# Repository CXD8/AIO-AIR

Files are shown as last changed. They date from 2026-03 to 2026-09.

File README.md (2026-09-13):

# AIO-AIR
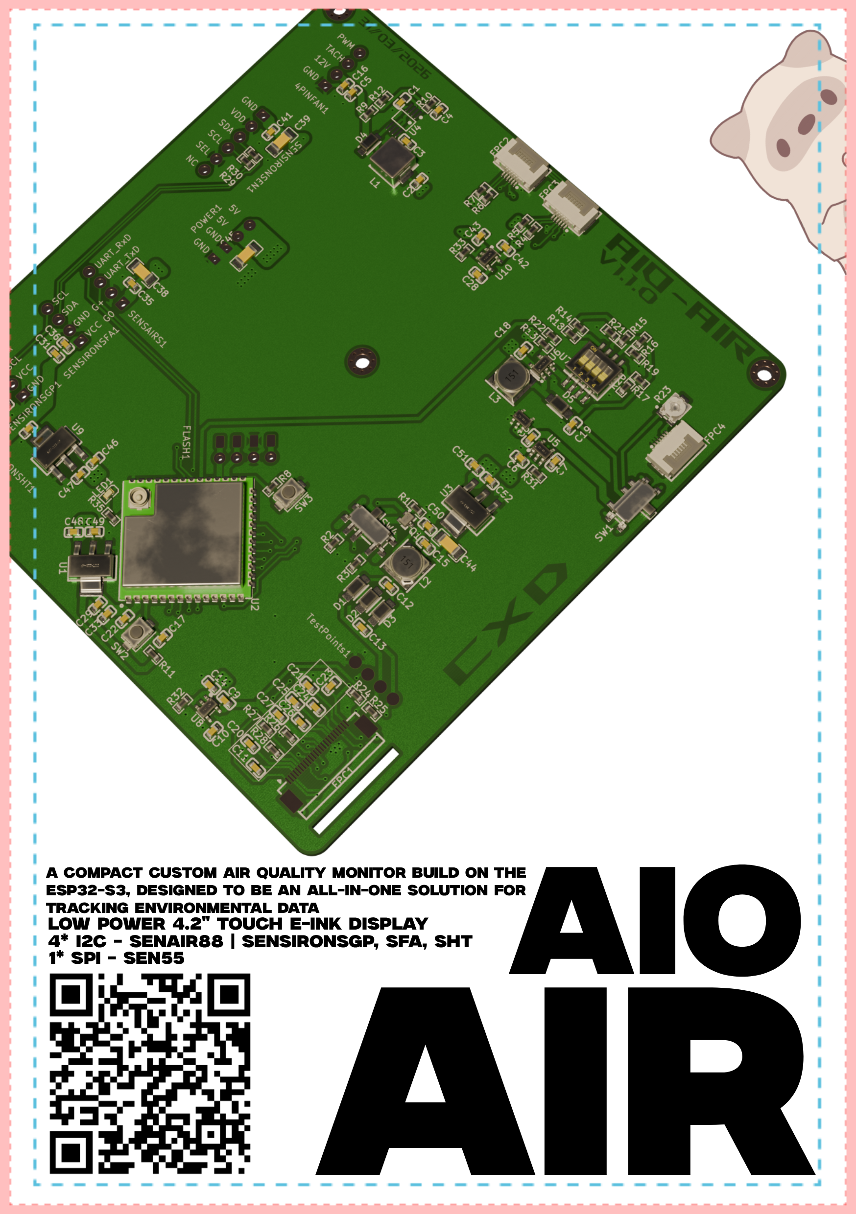
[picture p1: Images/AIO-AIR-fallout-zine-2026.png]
Poster
 \
**Project Overview**\
This is a compact, custom air quality monitor built around the ESP32-S3. I designed it to be an all-in-one solution for tracking environmental data, giving me a much better understanding of the air quality in my workspace.\
## Disclaimer
- **This project is intended for educational and research purposes only**
- **The author accepts no liability for regulatory non-compliance resulting from use of this project**
- **Users are solely responsible for ensuring compliance with all applicable local laws and regulations**
This project is provided **as-is, with absolutely no warranty of any kind**, express or implied. The author(s) accept **zero responsibility or liability** for any outcome resulting from the use, assembly, or operation of this hardware - including but not limited to property damage, fire, personal injury, or death.

**Use entirely at your own risk. The author(s) have no responsibility whatsoever for anything that goes wrong.**
- **Regulatory Disclaimer**
This project may use uncertified radio frequency (RF) modules. These components may have not been independently tested or certified for compliance such as for FCC (USA), CE (EU), or any other regulatory framework.
ard.**. The author(s) accept no responsibility for any damage, injury, or death caused.
- **No certification.** This design has not been tested, certified, or approved for any commercial, consumer, safety-critical, or regulatory-controlled application.
- **No guarantees.** The author(s) make no guarantees regarding the accuracy or fitness for purpose of the schematic, BOM, firmware, or any associated documentation.
**By using, building, or operating this project in any form, you accept full and sole responsibility for all risks and any consequences that arise.**
By using this project in any form, you agree to assume all associated risks and responsibilities.

**How to Use**\
Flashing: No integrated usb flashing feature. You can use your choice of usb flashing device eg FT or CH chipsets, connect them respectively on the PCB via the headers. Copy firmware into Ardiuno IDE or preffered flashing software, then flash directly.\
Integration: The device is built to talk directly to Home Assistant via ESPHome/MQTT. Once you flash the firmware, it will show up as a sensor entity on your dashboard.\
Features: You can view real-time data on your dashboard or through the low power e ink display. Optional fan with control and speed, status etc. Flexible desing, connect any device to the respective power, uart or spi pins.\

**Why I Built This**\
Many makers do soldering, 3D printing, and working with various materials in an enclosed space.I designed this board to get accurate, reliable readings so I can actually manage the air quality while I work. Also for monitoring Co2 because sleep is important :) |
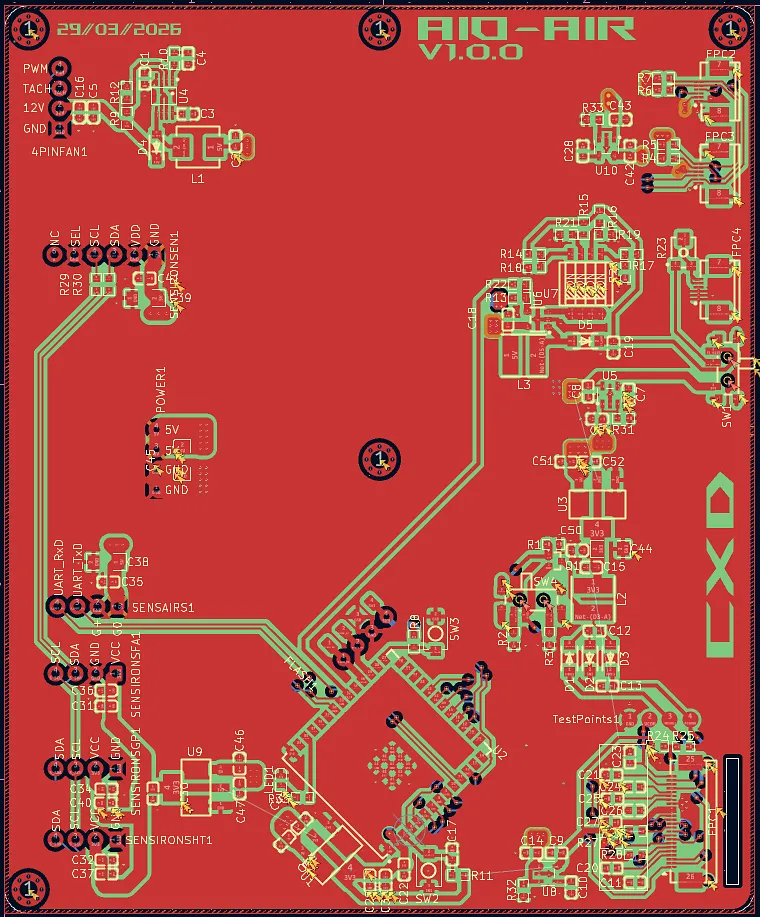
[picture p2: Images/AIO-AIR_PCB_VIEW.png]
PCB_VIEW
 \

Bill Of Materials
| **#** | **bom\.csv** | ****  | ****  | **** | **** | ****  | **** | **** | **** | **** | **** | **** | **** | **** | **** | **** | **** | **** | **** | **** | **** | **** | **** | **** | **** | **** |
|---|---|---|---|---|---|---|---|---|---|---|---|---|---|---|---|---|---|---|---|---|---|---|---|---|---|---|
| 1 | | | | | | | | | | | BOM Date Created:23/05/26 | | | | BOM Export Date: 23/05/26 | | | | | | | | | | | |
| 2 | | | | | | | | | | | EST LCSC TOTAL: $30\.73 | | | | | | | | | | | | | | | |
| 3 | | | | | | | | | | | TOTAL – 1 SEN55 Sensor: $92\.61 | | | | | | | | | | | | | | | |
| 4 | Uploaded data | | | | | | | | | | LCSC Matching Results | | | | | | | | | | | | | | | |
| 5 | LCSC\# | Mfr\. | Mrf\# | Description | Package | Value | Customer Part Number | Quantity | Target Price\(USD\) | Target Lead Time\(Business Days\) | Mrf\# | Mfr\. | Order Qty\. | Unit Price\(USD\) | Ext\.Price\(USD\) | LCSC\# | Package | Min  | Mult | SPQ  | Availability | Stock Status  | Customer Notes | Description | Matched status | Product Link |
| 6 | C15849 | | | | C0603 | | \- | 11 | | | CL10A105KB8NNNC | Samsung Electro\-Mechanics | 50 | 0\.0077 | 0\.39 | C15849 | 0603 | 50 | 50 | 4000 | 4032550 | In Stock | | 1uF ±10% 50V Ceramic Capacitor X5R 0603 | Exact Matches  | https://www\.lcsc\.com/product\-detail/C15849\.html |
| 7 | C96446 | | | | C0603 | | \- | 10 | | | CL10A106MA8NRNC | Samsung Electro\-Mechanics | 20 | 0\.0223 | 0\.45 | C96446 | 0603 | 20 | 20 | 4000 | 277300 | In Stock | | 10uF ±20% 25V Ceramic Capacitor X5R 0603 | Exact Matches  | https://www\.lcsc\.com/product\-detail/C96446\.html |
| 8 | C1591 | | | | C0603 | | \- | 10 | | | CL10B104KB8NNNC | Samsung Electro\-Mechanics | 100 | 0\.0032 | 0\.32 | C1591 | 0603 | 100  | 100  | 4000 | 1456500 | In Stock | | 100nF ±10% 50V Ceramic Capacitor X7R 0603 | Exact Matches  | https://www\.lcsc\.com/product\-detail/C1591\.html |
| 9 | C307467 | | | | C0603 | | \- | 4 | | | CL10A475KL8NRNC | Samsung Electro\-Mechanics | 5 | 0\.0304 | 0\.15 | C307467 | 0603 | 5 | 5 | 4000 | 192075 | In Stock | | 4\.7uF ±10% 35V Ceramic Capacitor X5R 0603 | Exact Matches  | https://www\.lcsc\.com/product\-detail/C307467\.html |
| 10 | C883598 | | | | C1206 | | \- | 4 | | | GRM31CR61A107MEA8L | muRata | 5 | 0\.1955 | 0\.98 | C883598 | 1206 | 5 | 5 | 2000 | 209960 | In Stock | | 100uF ±20% 10V Ceramic Capacitor X5R 1206 | Exact Matches  | https://www\.lcsc\.com/product\-detail/C883598\.html |
| 11 | C21122 | | | | C0603 | | \- | 3 | | | CL10B223KB8NNNC | Samsung Electro\-Mechanics | 50 | 0\.0046 | 0\.23 | C21122 | 0603 | 50 | 50 | 4000 | 1335100 | In Stock | | 22nF ±10% 50V Ceramic Capacitor X7R 0603 | Exact Matches  | https://www\.lcsc\.com/product\-detail/C21122\.html |
| 12 | C307467 | | | | C0603 | | \- | 3 | | | CL10A475KL8NRNC | Samsung Electro\-Mechanics | 5 | 0\.0304 | 0\.15 | C307467 | 0603 | 5 | 5 | 4000 | 192075 | In Stock | | 4\.7uF ±10% 35V Ceramic Capacitor X5R 0603 | Exact Matches  | https://www\.lcsc\.com/product\-detail/C307467\.html |
| 13 | C6119851 | | | | C0603 | | \- | 2 | | | CGA0603X5R475K350JT | HRE | 20 | 0\.0304 | 0\.61 | C6119851  | 0603 | 20 | 20 | 4000 | 18100 | In Stock | | 4\.7uF ±10% 35V Ceramic Capacitor X5R 0603 | Exact Matches  | https://www\.lcsc\.com/product\-detail/C6119851\.html  |
| 14 | C1591 | | | | C0603 | | \- | 2 | | | CL10B104KB8NNNC | Samsung Electro\-Mechanics | 100 | 0\.0032 | 0\.32 | C1591 | 0603 | 100  | 100  | 4000 | 1456500 | In Stock | | 100nF ±10% 50V Ceramic Capacitor X7R 0603 | Exact Matches  | https://www\.lcsc\.com/product\-detail/C1591\.html |
| 15 | C6563232 | | | | C0603 | | \- | 1 | | | 0603B112K500NT | FH | 100 | 0\.0030 | 0\.30 | C6563232  | 0603 | 100  | 100  | 4000 | 400 | In Stock | | 1\.1nF ±10% 50V Ceramic Capacitor X7R 0603 | Exact Matches  | https://www\.lcsc\.com/product\-detail/C6563232\.html  |
| 16 | C1591 | | | | C0603 | | \- | 1 | | | CL10B104KB8NNNC | Samsung Electro\-Mechanics | 100 | 0\.0032 | 0\.32 | C1591 | 0603 | 100  | 100  | 4000 | 1456500 | In Stock | | 100nF ±10% 50V Ceramic Capacitor X7R 0603 | Exact Matches  | https://www\.lcsc\.com/product\-detail/C1591\.html |
| 17 | C86295 | | | | C0603 | | \- | 1 | | | CL10A226MP8NUNE | Samsung Electro\-Mechanics | 10 | 0\.0157 | 0\.16 | C86295 | 0603 | 10 | 10 | 3000 | 1989760 | In Stock | | 22uF ±20% 10V Ceramic Capacitor X5R 0603 | Exact Matches  | https://www\.lcsc\.com/product\-detail/C86295\.html |
| 18 | C98220 | | | | R0603 | | \- | 5 | | | RC0603FR\-0710KL | YAGEO | 100 | 0\.0015 | 0\.15 | C98220 | 0603 | 100  | 100  | 5000 | 0 | Backordered | | 100mW 10k? 75V Thick Film Resistor ±100ppm/? ±1% 0603 Chip Resistor \- Surface Mount RoHS | Exact Matches  | https://www\.lcsc\.com/product\-detail/C98220\.html |
| 19 | C14675 | | | | R0603 | | \- | 5 | | | RC0603FR\-07100KL | YAGEO | 100 | 0\.0014 | 0\.14 | C14675 | 0603 | 100  | 100  | 5000 | 1073900 | In Stock | | 100mW 100k? 75V Thick Film Resistor ±100ppm/? ±1% 0603 Chip Resistor \- Surface Mount RoHS | Exact Matches  | https://www\.lcsc\.com/product\-detail/C14675\.html |
| 20 | C25804 | | | | R0603 | | \- | 4 | | | 0603WAF1002T5E | UNI\-ROYAL | 100 | 0\.0014 | 0\.14 | C25804 | 0603 | 100  | 100  | 5000 | 0 | Backordered | | 10k? ±1% 100mW 0603 Thick Film Resistor | Exact Matches  | https://www\.lcsc\.com/product\-detail/C25804\.html |
| 21 | C95177 | | | | R0603 | | \- | 4 | | | RC0603JR\-070RL | YAGEO | 100 | 0\.0014 | 0\.14 | C95177 | 0603 | 100  | 100  | 5000 | 1026800 | In Stock | | 100mW 0? 75V Thick Film Resistor ±5% 0603 Chip Resistor \- Surface Mount RoHS | Exact Matches  | https://www\.lcsc\.com/product\-detail/C95177\.html |
| 22 | C25804 | | | | R0603 | | \- | 2 | | | 0603WAF1002T5E | UNI\-ROYAL | 100 | 0\.0014 | 0\.14 | C25804 | 0603 | 100  | 100  | 5000 | 0 | Backordered | | 10k? ±1% 100mW 0603 Thick Film Resistor | Exact Matches  | https://www\.lcsc\.com/product\-detail/C25804\.html |
| 23 | C114659 | | | | R0603 | | \- | 2 | | | RC0603FR\-0712KL | YAGEO | 100 | 0\.0016 | 0\.16 | C114659 | 0603 | 100  | 100  | 5000 | 1073600 | In Stock | | 12k? 100mW 75V Thick Film Resistor ±100ppm/? ±1% 0603 Chip Resistor \- Surface Mount RoHS | Exact Matches  | https://www\.lcsc\.com/product\-detail/C114659\.html |
| 24 | C52069115 | | | | R0603 | | \- | 1 | | | MFCR0603F3R00Q9R | RESI | 5 | 0\.0840 | 0\.42 | C52069115 | 0603 | 5 | 5 | 5000 | 4610 | In Stock | | 3? 400mW ±50ppm/? ±1% 0603 Chip Resistor \- Surface Mount RoHS | Exact Matches  | https://www\.lcsc\.com/product\-detail/C52069115\.html |
| 25 | C23411 | | | | R0603 | | \- | 1 | | | 0603WAF470LT5E | UNI\-ROYAL | 100 | 0\.0051 | 0\.51 | C23411 | 0603 | 100  | 100  | 5000 | 59400 | In Stock | | 470m? ±1% 100mW 0603 Thick Film Resistor | Exact Matches  | https://www\.lcsc\.com/product\-detail/C23411\.html |
| 26 | C22883 | | | | R0603 | | \- | 1 | | | 0603WAF1583T5E | UNI\-ROYAL | 100 | 0\.0014 | 0\.14 | C22883 | 0603 | 100  | 100  | 5000 | 166400 | In Stock | | 158k? ±1% 100mW 0603 Thick Film Resistor | Exact Matches  | https://www\.lcsc\.com/product\-detail/C22883\.html |
| 27 | C107231 | | | | R0603 | | \- | 1 | | | RC0603FR\-0751KL | YAGEO | 100 | 0\.0016 | 0\.16 | C107231 | 0603 | 100  | 100  | 5000 | 140700 | In Stock | | 100mW 51k? 75V Thick Film Resistor ±100ppm/? ±1% 0603 Chip Resistor \- Surface Mount RoHS | Exact Matches  | https://www\.lcsc\.com/product\-detail/C107231\.html |
| 28 | C22892 | | | | R0603 | | \- | 1 | | | 0603WAF1822T5E | UNI\-ROYAL | 100 | 0\.0012 | 0\.12 | C22892 | 0603 | 100  | 100  | 5000 | 17100 | In Stock | | 18\.2k? ±1% 100mW 0603 Thick Film Resistor | Exact Matches  | https://www\.lcsc\.com/product\-detail/C22892\.html |
| 29 | C105574 | | | | R0603 | | \- | 1 | | | RC0603FR\-07200KL | YAGEO | 100 | 0\.0016 | 0\.16 | C105574 | 0603 | 100  | 100  | 5000 | 196200 | In Stock | | 100mW 200k? 75V Thick Film Resistor ±100ppm/? ±1% 0603 Chip Resistor \- Surface Mount RoHS | Exact Matches  | https://www\.lcsc\.com/product\-detail/C105574\.html |
| 30 | C2930091 | | | | R0603 | | \- | 1 | | | FRC0603F3003TS | FOJAN | 100 | 0\.0011 | 0\.11 | C2930091  | 0603 | 100  | 100  | 5000 | 1794600 | In Stock | | 300k? ±1% 100mW 0603 Thick Film Resistor | Exact Matches  | https://www\.lcsc\.com/product\-detail/C2930091\.html  |
| 31 | C105579 | | | | R0603 | | \- | 1 | | | RC0603FR\-0747KL | YAGEO | 100 | 0\.0016 | 0\.16 | C105579 | 0603 | 100  | 100  | 5000 | 370600 | In Stock | | 100mW 47k? 75V Thick Film Resistor ±100ppm/? ±1% 0603 Chip Resistor \- Surface Mount RoHS | Exact Matches  | https://www\.lcsc\.com/product\-detail/C105579\.html |
| 32 | C2998085 | | | | R0603 | | \- | 1 | | | FRC0603F9001TS | FOJAN | 0 | \- | \- | C2998085  | 0603 | 100  | 100  | 5000 | 0 | discountinued | | 9k? ±1% 100mW 0603 Thick Film Resistor | Exact Matches  | https://www\.lcsc\.com/product\-detail/C2998085\.html  |
| 33 | C109318 | | | | R0603 | | \- | 1 | | | RC0603FR\-0710RL | YAGEO | 100 | 0\.0039 | 0\.39 | C109318 | 0603 | 100  | 100  | 5000 | 3822900 | In Stock | | 100mW 10? 75V Thick Film Resistor ±1% ±200ppm/? 0603 Chip Resistor \- Surface Mount RoHS | Exact Matches  | https://www\.lcsc\.com/product\-detail/C109318\.html |
| 34 | C22461457 | | | | RES\-ADJ\-SMD\_3P\-L3\.8\-W3\.7\_VGF39NCHXT  | | \- | 1 | | | VGF39NCHXT\-B201 | HDK | 5 | 0\.1107 | 0\.55 | C22461457 | SMD\-3P,3\.8x3\.7mm | 5 | 5 | 2500 | 2525 | In Stock | | 200? ±25% 150mW SMD Potentiometers, Variable Resistors | Exact Matches  | https://www\.lcsc\.com/product\-detail/C22461457\.html |
| 35 | C105881 | | | | R0603 | | \- | 1 | | | RC0603FR\-07330RL | YAGEO | 100 | 0\.0015 | 0\.15 | C105881 | 0603 | 100  | 100  | 5000 | 351200 | In Stock | | 100mW 330? 75V Thick Film Resistor ±100ppm/? ±1% 0603 Chip Resistor \- Surface Mount RoHS | Exact Matches  | https://www\.lcsc\.com/product\-detail/C105881\.html |
| 36 | C2875591 | | | | IND\-SMD\_L4\.7\-W4\.7 | | \- | 2 | | | CDH4D28N\-100M | MINGSTAR | 5 | 0\.1803 | 0\.90 | C2875591  | SMD,4\.7x4\.7mm | 5 | 5 | 2500 | 2505 | In Stock | | 1A 10uH ±20% 128\.3m? SMD,4\.7x4\.7mm Fixed Inductors RoHS | Exact Matches  | https://www\.lcsc\.com/product\-detail/C2875591\.html  |
| 37 | C436534 | | | | IND\-SMD\_L5\.4\-W5\.2\_PSPMAA0503 | | \- | 1 | | | PSPMAA0503\-3R3M\-ANP | PROD Tech | 5 | 0\.1292 | 0\.65 | C436534 | SMD,5\.4x5\.2mm | 5 | 5 | 2000 | 4805 | In Stock | | 5A 3\.3uH ±20% 6A 38m? SMD,5\.4x5\.2mm Fixed Inductors RoHS | Exact Matches  | https://www\.lcsc\.com/product\-detail/C436534\.html |
| 38 | C7436545 | | | | SOD\-123\_L2\.8\-W1\.8\-LS3\.9\-FD | | \- | 4 | | | MBR0530T1G | FUXINSEMI | 10 | 0\.0162 | 0\.16 | C7436545  | SOD\-123 | 10 | 10 | 3000 | 5700 | In Stock | | Diode Independent 30V 0\.5A Surface Mount SOD\-123 | Exact Matches  | https://www\.lcsc\.com/product\-detail/C7436545\.html  |
| 39 | C110921 | | | | SOD\-123F\_L2\.8\-W1\.8\-LS3\.7\-RD | | \- | 1 | | | PMEG2010AEH,115 | Nexperia | 5 | 0\.2158 | 1\.08 | C110921 | SOD\-123F | 5 | 5 | 3000 | 5360 | In Stock | | Diode 1 Independent 20V 1A Surface Mount SOD\-123F | Exact Matches  | https://www\.lcsc\.com/product\-detail/C110921\.html |
| 40 | C150716 | | | | SOT\-223\_L6\.7\-W3\.5\-P2\.30\-BR | | \- | 3 | | | AP2114H\-3\.3TRG1 | DIODES | 5 | 0\.1763 | 0\.88 | C150716 | SOT\-223 | 5 | 5 | 4000 | 14765 | In Stock | | 3\.3V Positive Fixed SOT\-223 Voltage Regulators \- Linear, Low Drop Out \(LDO\) Regulators RoHS | Exact Matches  | https://www\.lcsc\.com/product\-detail/C150716\.html |
| 41 | C15651 | | | | SOT\-23\-5\_L3\.0\-W1\.7\-P0\.95\-LS2\.8\-BL | | \- | 3 | | | RT9193\-33GB | RICHTEK | 5 | 0\.1271 | 0\.64 | C15651 | SOT\-23\-5 | 5 | 5 | 3000 | 0 | Backordered | | 3\.3V Positive Fixed SOT\-23\-5 Voltage Regulators \- Linear, Low Drop Out \(LDO\) Regulators RoHS | Exact Matches  | https://www\.lcsc\.com/product\-detail/C15651\.html |
| 42 | C3013946 | | | | WIRELM\-SMD\_ESP32\-S3\-WROOM\-1U | | \- | 1 | | | ESP32\-S3\-WROOM\-1U\-N16R8 | ESPRESSIF | 1 | 5\.5217 | 5\.52 | C3013946  | SMD,19\.2x18mm | 1 | 1 | 650  | 0 | Backordered | | 2\.4GHz ESP32\-S3R8 \-103\.5dBm SMD,19\.2x18mm RF Transceiver Modules and Modems RoHS | Exact Matches  | https://www\.lcsc\.com/product\-detail/C3013946\.html  |
| 43 | C113659 | | | | VSSOP\-8\_L3\.0\-W3\.0\-P0\.65\-LS5\.0\-BL | | \- | 1 | | | TPS61085DGKR | TI | 1 | 0\.5915 | 0\.59 | C113659 | VSSOP\-8\-0\.65mm | 1 | 1 | 2500 | 4530 | In Stock | | Boost Adjustable 2\.8V~18\.5V 2A 2\.3V~6V VSSOP\-8\-0\.65mm Voltage Regulators \- DC DC Switching Regulators RoHS | Exact Matches  | https://www\.lcsc\.com/product\-detail/C113659\.html |
| 44 | C664389 | | | | SOT\-23\-5\_L3\.0\-W1\.6\-P0\.95\-LS2\.8\-BL | | \- | 1 | | | LT1615IS5\#TRPBF | ADI | 1 | 6\.0924 | 6\.09 | C664389 | TSOT\-23\-5 | 1 | 1 | 2500 | 143 | In Stock | | Boost Adjustable 1V~15V 1\.23V~34V 300mA TSOT\-23\-5 Voltage Regulators \- DC DC Switching Regulators RoHS | Exact Matches  | https://www\.lcsc\.com/product\-detail/C664389\.html |
| 45 | C3293144 | | | | SW\-SMD\_8P\-L6\.7\-W5\.4\-P1\.27\-LS8\.4 | | \- | 1 | | | DSHP04TSGER | kangshen | 4 | 0\.5202 | 2\.08 | C3293144  | SMD,P=1\.27mm | 4 | 4 | 2000 | 29172 | In Stock | | Dip Switch SPST 4 Position Surface Mount\-8P,5\.4x6\.6mm 25mA 24V | Exact Matches  | https://www\.lcsc\.com/product\-detail/C3293144\.html  |
| 46 | C963206 | | | | SW\-SMD\_MK\-12C02\-G020 | | \- | 2 | | | MK\-12C02\-G020 | G\-Switch | 5 | 0\.1168 | 0\.58 | C963206 | SMD,6\.6x1\.4mm | 5 | 5 | 3000 | 9555 | In Stock | | Slide Switch SPDT 1A @ 6V Surface Mount, Right Angle Rectangular Columnar 6\.6mm | Exact Matches  | https://www\.lcsc\.com/product\-detail/C963206\.html |
| 47 | C720477 | | | | SW\-SMD\_L3\.9\-W3\.0\-P4\.45 | | \- | 2 | | | TS\-1088\-AR02016 | XUNPU | 10 | 0\.0538 | 0\.54 | C720477 | SMD,4x3mm | 10 | 10 | 4000 | 582850 | In Stock | | Tactile Switch SPST 160gf 2mm SMD \(SMT\) Tab 4mm x 3mm Surface Mount | Exact Matches  | https://www\.lcsc\.com/product\-detail/C720477\.html |
| 48 | C2856796 | | | | FPC\-SMD\_6P\-P0\.50\_XUNPU\_FPC\-05F\-6PH20 | | \- | 3 | | | FPC\-05F\-6PH20 | XUNPU | 5 | 0\.1000 | 0\.50 | C2856796  | SMD,P=0\.5mm,Surface Mount,Right Angle | 5 | 5 | 2000 | 66135 | In Stock | | FFC/FPC Connector 6 Position 0\.5mm Pitch Bottom Contact Surface Mount, Right Angle \-25?~\+85? | Exact Matches  | https://www\.lcsc\.com/product\-detail/C2856796\.html  |
| 49 | C240840 | | | | 4PIN\_FAN\_PWM | | \- | 1 | | | 470531000 | MOLEX | 5 | 0\.1803 | 0\.90 | C240840 | Through Hole,P=2\.54mm | 5 | 5 | 1000 | 21670 | In Stock | | Connector Header 4 position 2\.54mm Pitch Through Hole | Exact Matches  | https://www\.lcsc\.com/product\-detail/C240840\.html |
| 50 | | | | | FLASH | | \- | 1 | | | \- | \- | \- | \- | \- | \- | \- | \- | \- | \- | \- | \- | | \- | \- | |
| 51 | C3446015 | | | | FPC\-SMD\_XUNPU\-FPC\-0\.5FX\-24PWBH20 | | \- | 1 | | | FPC\-0\.5FX\-24PWBH20 | XUNPU | 5 | 0\.1424 | 0\.71 | C3446015  | SMD,P=0\.5mm | 5 | 5 | 2000 | 3065 | In Stock | | Hinged Lid \-25?~\+85? 24P 0\.5mm 500mA 50V Tin Bottom Contact Surface Mount, Right Angle Phosphor bronze SMD,P=0\.5mm FFC, FPC \(Flat Flexible\) Connector Assemblies RoHS | Exact Matches  | https://www\.lcsc\.com/product\-detail/C3446015\.html  |
| 52 | C219228 | | | | LED\-SMD\_L1\.6\-W0\.8\-RD\-WHITE\-2 | | \- | 1 | | | HL\-PST\-1608H233W\(8000\-12000K\) | HONGLITRONIC | 20 | 0\.0197 | 0\.39 | C219228 | 0603 | 20 | 20 | 4000 | 73360 | In Stock | | White LED Indication \- Discrete 3\.3V 0603 | Exact Matches  | https://www\.lcsc\.com/product\-detail/C219228\.html |
| 53 | https://www\.aliexpress\.com/item/1005009258276115\.html | | | | 4\.2”E\-INK | | \- | 1 | | | GDEY042T81\-T02 | GooDisplay | 1 | 22\.46 | 22\.46 | \- | \- | \- | \- | \- | \- | \- | | \- | ALIEXPRESS | |
| 54 | C3289597 | | | | SOT\-323\_L2\.0\-W1\.3\-P1\.30\-LS2\.1\-BR | | \- | 1 | | | SI1308EDL\-T1\-BE3 | VISHAY | 1 | 0\.4041 | 0\.40 | C3289597  | SC\-70\-3 | 1 | 1 | 3000 | 2243 | In Stock | | N\-Channel 30V 1\.5A 0\.5W Surface Mount SC\-70\-3 | Exact Matches  | https://www\.lcsc\.com/product\-detail/C3289597\.html  |
| 55 | https://www\.aliexpress\.com/item/1005008474655738\.html | | | | 24 PIN FPC CABLE | | \- | 1 | | | \- | \- | \- | 0\.99 | 0\.99 | \- | \- | \- | \- | \- | \- | \- | | \- | ALIEXPRESS | |
| 56 | https://www\.aliexpress\.com/item/1005006672233038\.html | | \- | | SEN55 | \- | \- | 1 | \- | \- | SEN55 | Sensirion | | 38\.43 | 38\.43 | \- | \- | \- | \- | \- | \- | \- | | \- | ALIEXPRESS | |

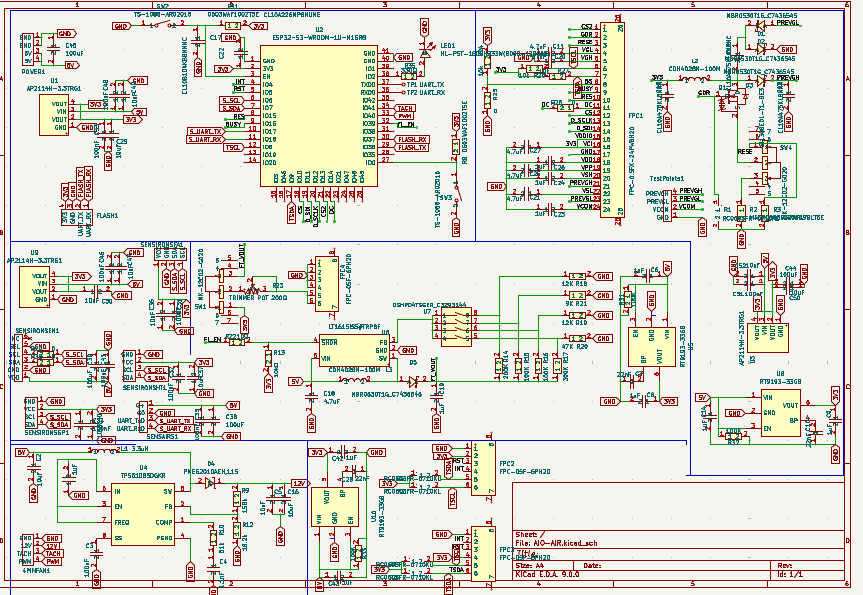
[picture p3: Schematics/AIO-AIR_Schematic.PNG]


Changelog\
06/30/2026
New Housing/Case. Improved viewing angles, fits larger sensors, looks much better.
03/31/2026
Optimise PCB size under 100mmx100mm for cheaper fabrication costs.
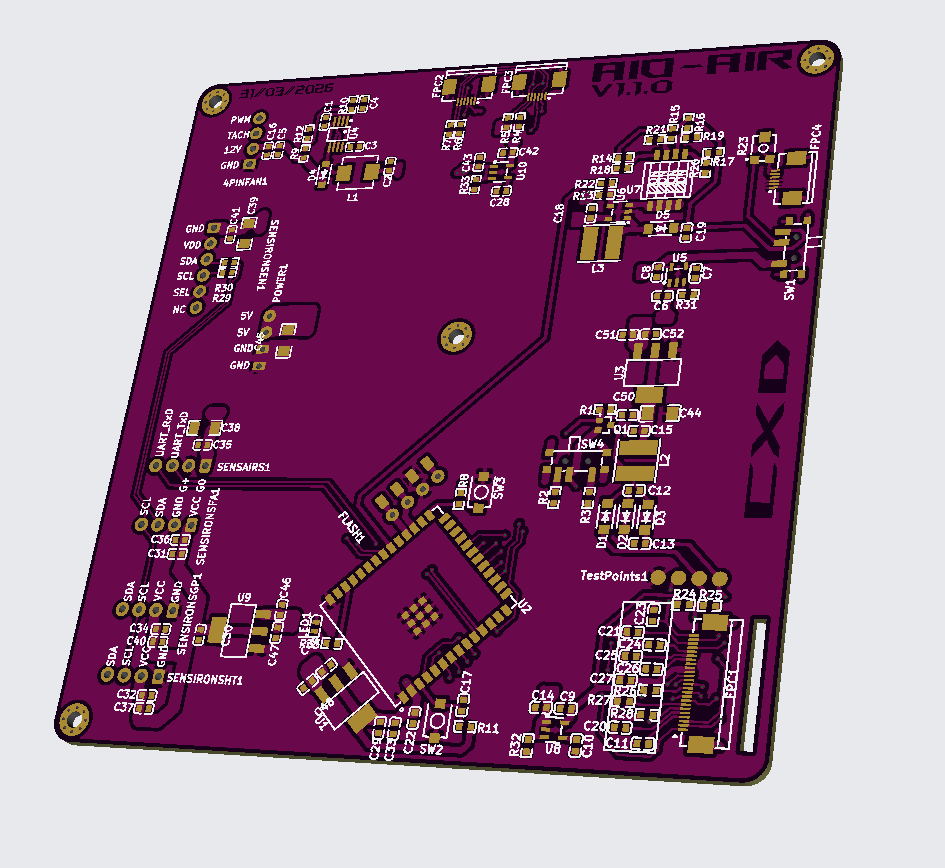
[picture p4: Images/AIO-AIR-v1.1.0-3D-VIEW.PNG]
PCB_VIEW


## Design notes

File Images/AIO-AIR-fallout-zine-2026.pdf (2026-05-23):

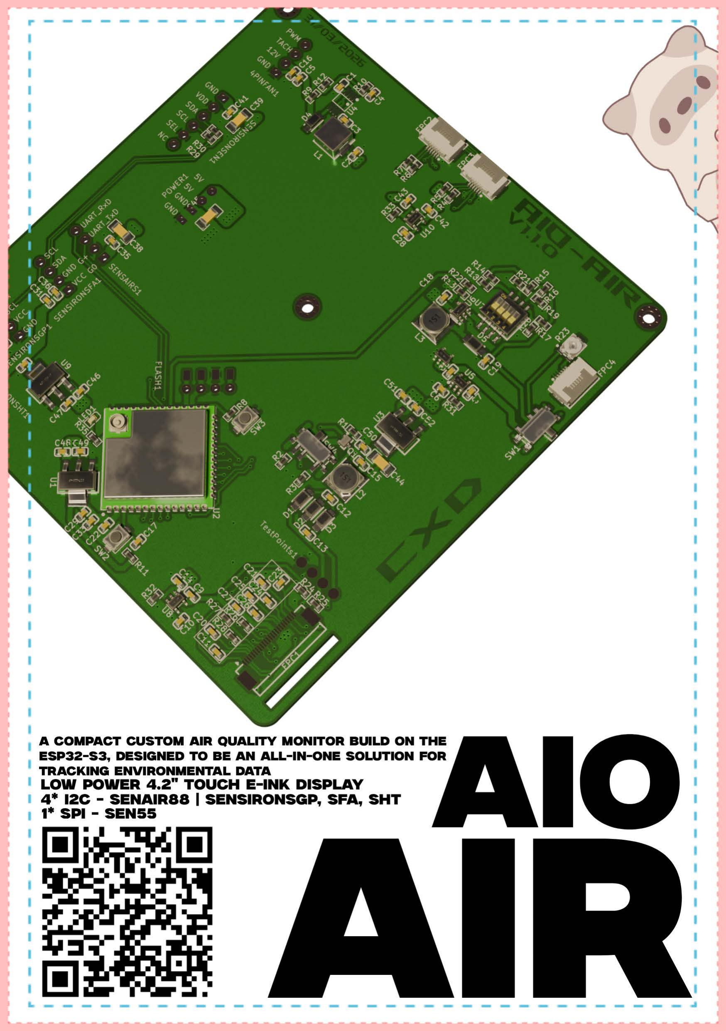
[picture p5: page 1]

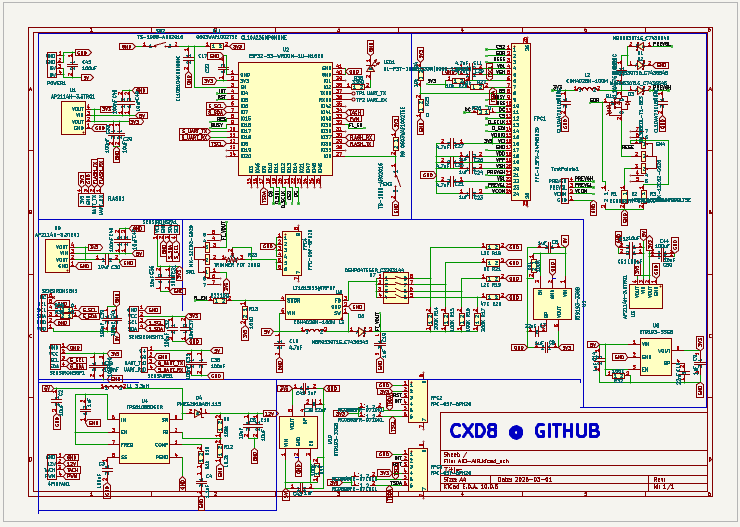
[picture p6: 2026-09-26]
Schematics/AIO-AIR-SCHEMATIC-PNG_release.PNG

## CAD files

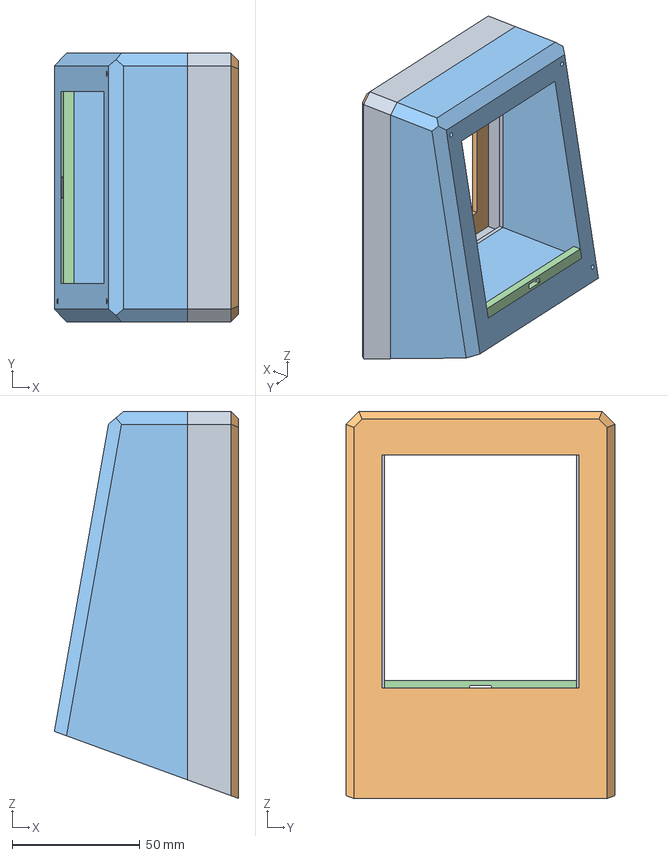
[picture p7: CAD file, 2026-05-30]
3D_Models/AIO-AIR-CASE-V2.step
72.0 x 105.0 x 151.2 mm

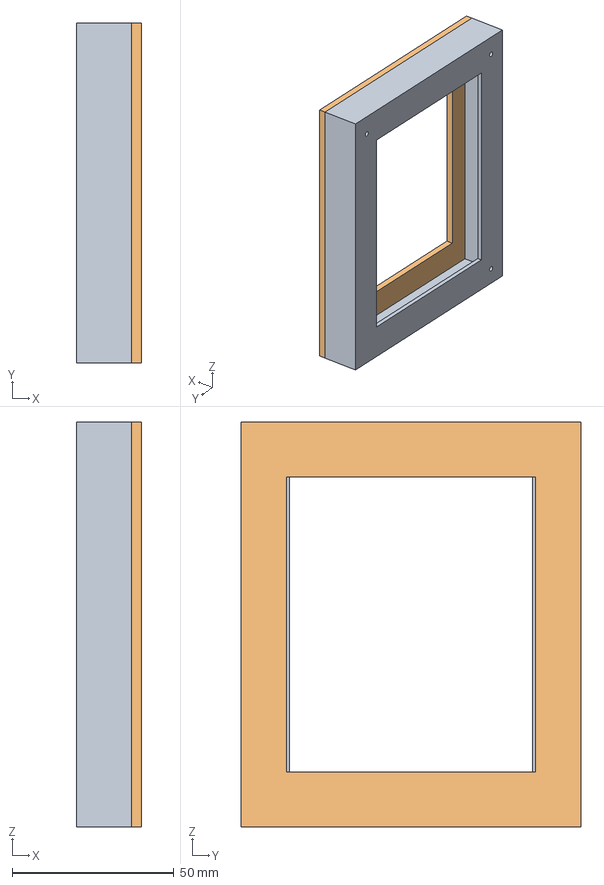
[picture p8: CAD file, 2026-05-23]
3D_Models/Housing_for_display_pcb.step
20.0 x 105.0 x 125.0 mm

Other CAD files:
3D_Models/AIO-AIR-CASE-V2.f3d
3D_Models/Housing_for_display_pcb.f3d
3D_Models/Housing_for_display_pcb.stl

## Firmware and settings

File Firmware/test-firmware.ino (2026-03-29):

#include <Arduino.h>
#include <Wire.h>

// I2C Bus 0 — Air sensors group 1 (up to 4 sensors)
#define BUS0_SCL  6   // IO6
#define BUS0_SDA  7   // IO7

// I2C Bus 1 — Display touch + eink touch (TSCL/TSDA)
#define BUS1_SCL  8   // IO8
#define BUS1_SDA  9   // IO9

TwoWire Bus0 = TwoWire(0);
TwoWire Bus1 = TwoWire(1);

void scanBus(TwoWire &bus, const char *busName) {
  Serial.printf("\n--- Scanning %s ---\n", busName);
  
  uint8_t found = 0;

  for (uint8_t addr = 0x01; addr < 0x7F; addr++) {
    bus.beginTransmission(addr);
    uint8_t error = bus.endTransmission();

    if (error == 0) {
      Serial.printf("  Device found at 0x%02X", addr);

      // Known device hints based on common addresses
      switch (addr) {
        // Sensirion SEN55
        case 0x69: Serial.print(" <- SEN55 (air quality)");       break;

        // Common CO2 sensors
        case 0x61: Serial.print(" <- SCD40/SCD41 (CO2)");         break;
        case 0x62: Serial.print(" <- SCD30 (CO2)");               break;

        // Common VOC / air sensors
        case 0x58: Serial.print(" <- SGP30 (VOC)");               break;
        case 0x59: Serial.print(" <- SGP40 (VOC)");               break;

        // Common touch controllers
        case 0x38: Serial.print(" <- FT6236 (touch)");            break;
        case 0x48: Serial.print(" <- ADS1115 or touch ctrl");     break;
        case 0x14: Serial.print(" <- GT911 (touch)");             break;
        case 0x5D: Serial.print(" <- GT911 alt addr (touch)");    break;

        // Common environmental sensors
        case 0x40: Serial.print(" <- SHT31 / HDC1080 (temp/hum)"); break;
        case 0x44: Serial.print(" <- SHT31 (temp/hum)");          break;
        case 0x45: Serial.print(" <- SHT31 alt addr");            break;
        case 0x76: Serial.print(" <- BME280 / BMP280");           break;
        case 0x77: Serial.print(" <- BME280 alt addr");           break;

        default: break;
      }
      Serial.println();
      found++;
    } else if (error == 4) {
      Serial.printf("  Error at 0x%02X (unknown error)\n", addr);
    }
  }

  if (found == 0) {
    Serial.println("  No devices found — check wiring and pull-ups");
  } else {
    Serial.printf("  Total: %d device(s) found\n", found);
  }
}

void setup() {
  Serial.begin(115200);
  while (!Serial) delay(10);

  delay(500);
  Serial.println("\n=============================");
  Serial.println(" I2C Bus Scanner");
  Serial.println("=============================");
  Serial.printf(" Bus 0: SDA=IO%d  SCL=IO%d\n", BUS0_SDA, BUS0_SCL);
  Serial.printf(" Bus 1: SDA=IO%d  SCL=IO%d\n", BUS1_SDA, BUS1_SCL);
  Serial.println("=============================");

  // Initialise both buses at 100kHz for reliable detection
  Bus0.begin(BUS0_SDA, BUS0_SCL, 100000);
  Bus1.begin(BUS1_SDA, BUS1_SCL, 100000);

  scanBus(Bus0, "Bus 0 - Air Sensors (IO6/IO7)");
  scanBus(Bus1, "Bus 1 - Touch / Display (IO8/IO9)");

  Serial.println("\nScan complete.");
  Serial.println("Run again by pressing reset.\n");
}

void loop() {
}

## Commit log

2026-04-01 Add Bill of Materials section to README
    Added a Bill of Materials (BOM) section to the README with detailed component specifications.
2026-04-01 Modify AIO-AIR_BOM.csv with corrections and additions
    Updated part values and added links for components.
    [AIO-AIR_BOM.csv]
2026-04-02 Update README.md
    Added disclaimers regarding project use, liability, and regulatory compliance. Expanded project overview and usage instructions.
2026-05-15 Clarify flashing instructions in README
    Updated flashing instructions for clarity and added details about using USB flashing devices.
2026-05-23 Update README with BOM details and images
    Added BOM table with detailed components and pricing.
2026-05-23 Rename bom (2).csv to bom.csv
    [bom (2).csv, bom.csv]
